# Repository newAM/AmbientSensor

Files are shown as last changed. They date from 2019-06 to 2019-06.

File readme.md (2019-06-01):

## Ambient Sensor

### What is it?
This project is a ambient environment sensor that gathers the luminosity, temperature, humidity, and pressure.  This data is transmitted in real time to my Home Assistant server via MQTT over Ethernet.

### Why?
I wanted to explore real-time adjustments of lighting, and window coverings to maintain constant light levels in a room, which requires high sample rates (multiple samples per second) for responsive adjustments.

When I started this project there were no high-sample rate luminosity sensors for home automation.  The devices that did exist either had low sample rates (minutes vs milliseconds), or were designed for scientific applications.

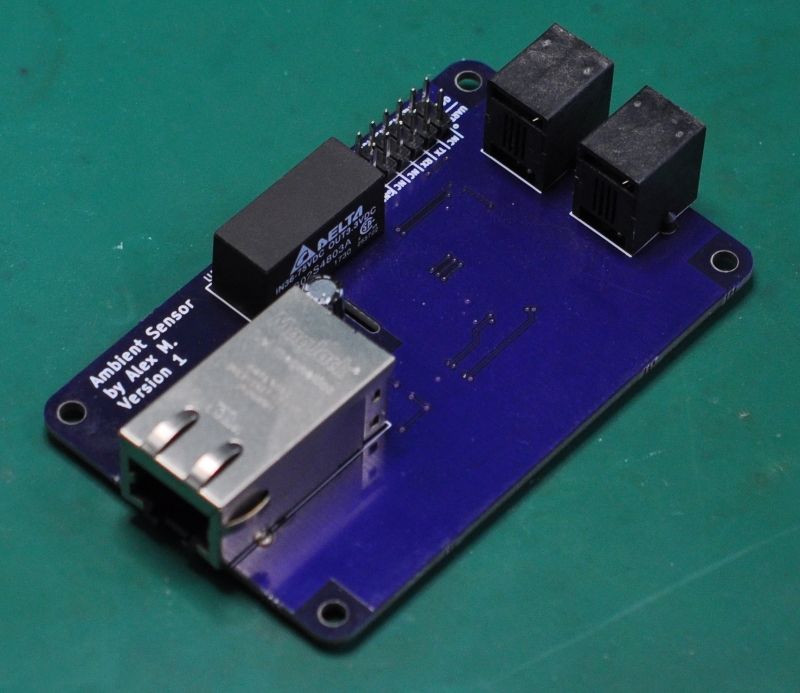
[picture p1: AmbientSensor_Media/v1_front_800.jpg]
v1_front_800


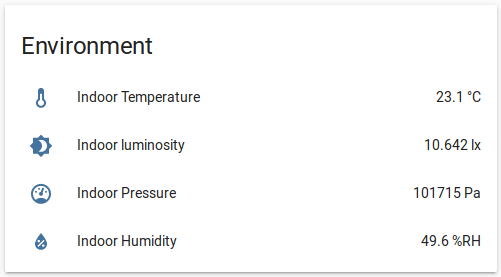
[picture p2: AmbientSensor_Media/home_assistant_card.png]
home_assistant_card


### Project Contents
* AmbientSensor_Code - firmware source code
* AmbientSensor_HomeAssisant - sample configuration for use with HomeAssistant
* AmbientSensor_KiCAD - schematic and PCB
* AmbientSensor_Peripheral - schematic and PCB for peripheral sensors
* AmbientSensor_Media - photos

### Prototype and Design
See [prototyping.md](prototyping.md) for the prototyping and design process.

### Software Used
* KiCAD 5.0.2
* GNU Make 4.1
* GNU gdb (GNU Tools for Arm Embedded Processors 7-2018-q3-update) 8.1.0.20180315
* GNU gcc (GNU Tools for Arm Embedded Processors 7-2018-q3-update) 7.3.1 20180622
* STM32CubeMX 5.1.0
* OpenOCD 0.10.0

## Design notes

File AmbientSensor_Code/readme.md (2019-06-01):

## Firmware README
The core code (HAL, FreeRTOS) was generated by [CubeMX](https://www.st.com/en/development-tools/stm32cubemx.html).  This is a piece of software from STM that generates all the boilerplate to get started with your STM32 microcontroller!  The code is already generated and in the repository; but I highly recommend using CubeMX if you need to change the auto-generated portions of the code.

### Windows Setup
Doing any sort of development with GNU tools on Windows is a pain.  I highly recommend dual booting Linux, running a virtual machine, or at the very least utilizing [Ubuntu on Windows](https://tutorials.ubuntu.com/tutorial/tutorial-ubuntu-on-windows).

### General Setup

Install packages
```
sudo apt install gcc-arm-none-eabi
sudo apt install gdb-arm-none-eabi
sudo apt install openocd
```

GDB for ARM may be covered by GDB multiarch for newer Ubuntu installs.  See [here](https://askubuntu.com/questions/1031103/how-to-install-gdb-arm-none-eabi-on-ubuntu-18-04).

### Building
CubeMX generates a tidy makefile for building the project.  There are other options that can tie into IDE's, but make is the only open source option.

### Call Make
Simply navigate into this directory and call make!

```
cd AmbientSensor_Code
make
```

The output will be available under `AmbientSensor_Code/build`.

### Programming and Debugging
The [ST-LINK/V2](https://www.st.com/en/development-tools/st-link-v2.html) is a cheap programmer and debugger for STM32 microcontrollers.

To use this with GDB I used [OpenOCD](http://openocd.org/), this exposes the USB debugger as a server that GDB can connect to.

On Linux the command to connect to the debugger looks like this
```
sudo openocd -f interface/stlink-v2.cfg -f target/stm32f0x.cfg
```

The OpenOCD server should then output something similar to:
```
Open On-Chip Debugger 0.10.0
Licensed under GNU GPL v2
For bug reports, read http://openocd.org/doc/doxygen/bugs.html
Info : auto-selecting first available session transport "hla_swd". To override use 'transport select <transport>'.
Info : The selected transport took over low-level target control. The results might differ compared to plain JTAG/SWD
adapter speed: 1000 kHz
adapter_nsrst_delay: 100
none separate
Info : Listening on port 6666 for tcl connections
Info : Listening on port 4444 for telnet connections
Info : Unable to match requested speed 1000 kHz, using 950 kHz
Info : Unable to match requested speed 1000 kHz, using 950 kHz
Info : clock speed 950 kHz
Info : STLINK v2 JTAG v28 API v2 SWIM v17 VID 0x0483 PID 0x374B
Info : using stlink api v2
Info : Target voltage: 3.260766
Info : stm32f0x.cpu: hardware has 4 breakpoints, 2 watchpoints
Info : Listening on port 3333 for gdb connections
```

Open GDB with this command:
```
arm-none-eabi-gdb build/AmbientSensor.elf
```

Then in the GDB interface you can connect to OpenOCD, reset the target and load the firmware.
```
(gdb) target remote localhost:3333
(gdb) monitor reset init
(gdb) monitor halt
(gdb) load
(gdb) c
```

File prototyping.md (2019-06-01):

## Overview
Ultimately, the input is the sensors, and the output is a value in Home Assistant
```
Sensors → STM32 Microcontroller → W5500 (TCP/IP + Ethernet PHY) → MQTT Server → Home Assistant
```

## Design Choices
### Sensors
There are two primary sensors for measuring the environment:
* [Bosch Sensortec BME280](https://www.bosch-sensortec.com/bst/products/all_products/bme280)
  * Temperature
  * Humidity
  * Pressure
* [Texas Instruments OPT3002](http://www.ti.com/product/OPT3002)
  * Luminosity

These sensors are connected to the main board with short RJ-11 cables that connect to the I2C bus on the microcontroller.
In the case of the BME280 the external connection was necessary to obtain accurate measurements, the main PCB is hotter than the ambient environment, and it would skew temperature readings.

For the OPT3002 the external connection is to allow for easy positioning of the sensor.

The BME280 was chosen over cheaper alternatives, such as the Aosong AM2032 (DHT22) because [this in depth review](http://www.kandrsmith.org/RJS/Misc/Hygrometers/calib_many.html#commentary) speaks highly of the BM280 as compared to similar devices.

### Microcontroller
The STM32F070CBTx was chosen because:
1. STM provides a very good hardware adapter layer (HAL) for their micro-controllers.
2. STM provides a FreeRTOS port for their micro-controllers.
3. I wanted to do something new, my past projects have been mostly AVR.

### Firmware
The firmware uses [FreeRTOS](https://www.freertos.org/) for scheduling, simply because it seemed like a fun learning experience, and it was!

The micro-controller has 4 main threads running:
1. A sampling thread for the BM280
2. A sampling thread for the OPT3002
3. DHCP client
4. MQTT client

The sampling threads take data from the sensors and place it in a queue for the MQTT task.
The MQTT client thread pops the samples from the queue and publishes them to the MQTT server.
The DHCP client thread handles the leasing of an IP from the DHCP server.

In the interest of learning new things I also made some poor choices intentionally; I implemented my own DHCP client code, and my own MQTT client code.  This was not the smart choice, since there are polished DHCP clients out there, such as the one in [LwIP](https://savannah.nongnu.org/projects/lwip/), but this was the _fun_ choice.

Instructions for using the firmware can be found [here](AmbientSensor_Code/readme.md).

## Prototyping
I wanted to get the PCB for this right on the first try, so I prototyped everything on a breadboard.

Naturally a lot of components were not available in 2.54mm friendly packages, I made some breadboard friendly boards for these components:
* [NCP1090](https://github.com/newAM/DevBoard_NCP1090)
* [OPT3002](https://github.com/newAM/Breakout_OPT3002)
* [W5500](https://github.com/newAM/DevBoard_W5500)
* [STM32F070CBTx](https://github.com/newAM/Breakout_STM32F070CBTx)
* [JTAG Adapter](https://github.com/newAM/Adapter_JTAG20PinTo6Pin)
* [PoE magjack 0813-1X1T-57-F](https://github.com/newAM/Breakout_0813-1X1T-57-F)

Debug tools used
* [ST-LINK/V2](https://www.st.com/en/development-tools/st-link-v2.html) - USB debugger/programmer
* [Saleae Logic 8](https://cad.saleae.com/products/saleae-logic-8?variant=6998355738685) - USB Logic analyzer
* [TP-Link TL-POE150S Injector](https://www.tp-link.com/us/business-networking/accessory/tl-poe150s/) - PoE Injector
* [FTDI Friend v1.0](https://www.adafruit.com/product/284) - USB to serial adapter

### Prototype Media
#### Breadboard Prototype
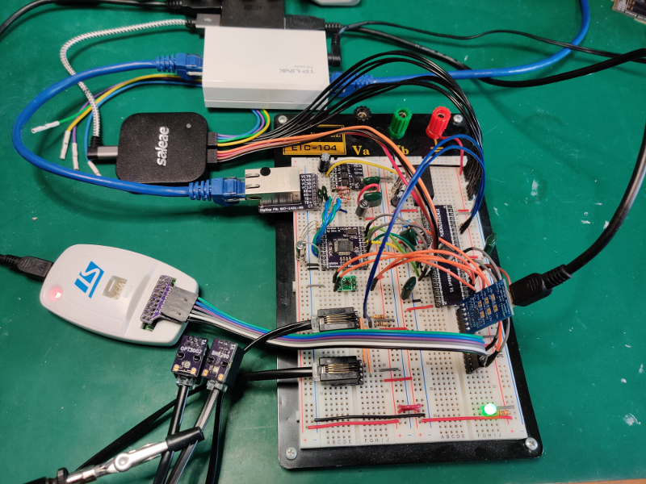
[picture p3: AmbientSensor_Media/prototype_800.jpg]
prototype_800


#### Prototype Thermal
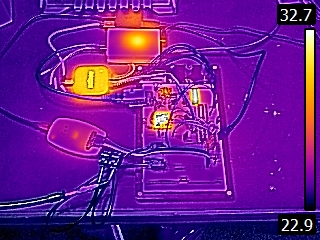
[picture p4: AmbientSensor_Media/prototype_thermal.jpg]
prototype_thermal


## V1 Hardware
The PCB is bigger than it needs to be because I was using the sample footprint that I have used for previous projects.
* [LoadCellOccupancy](https://github.com/newAM/LoadCellOccupany)
* [FanController](https://github.com/newAM/FanController)

### V1 Hardware Sensors
The sensors are on their own PCB with an RJ-11 connector.

#### BME280 sensor
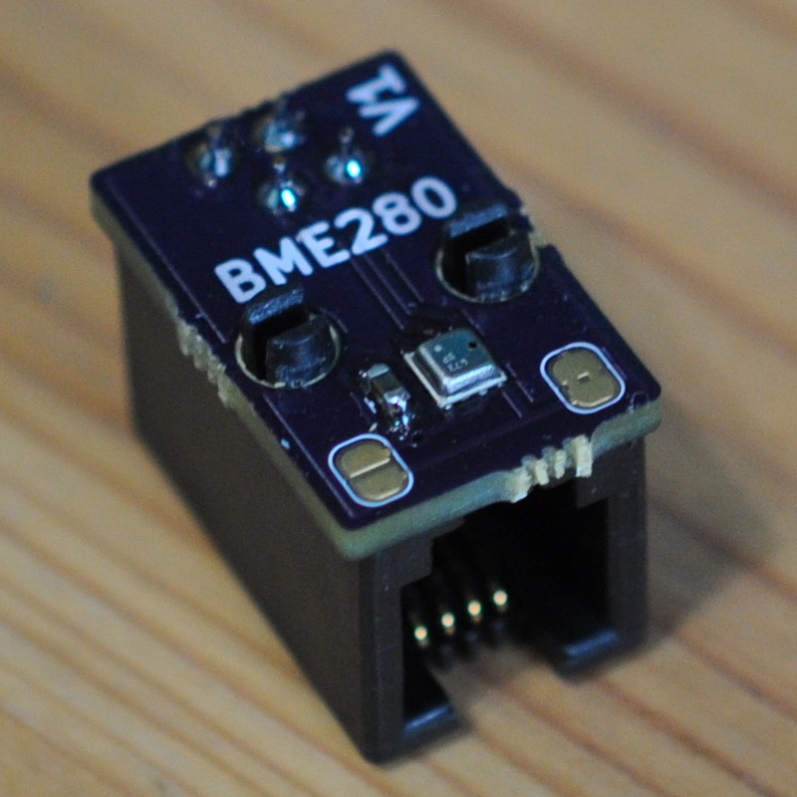
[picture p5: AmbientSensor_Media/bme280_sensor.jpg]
bme280_sensor


#### OPT3002 sensor
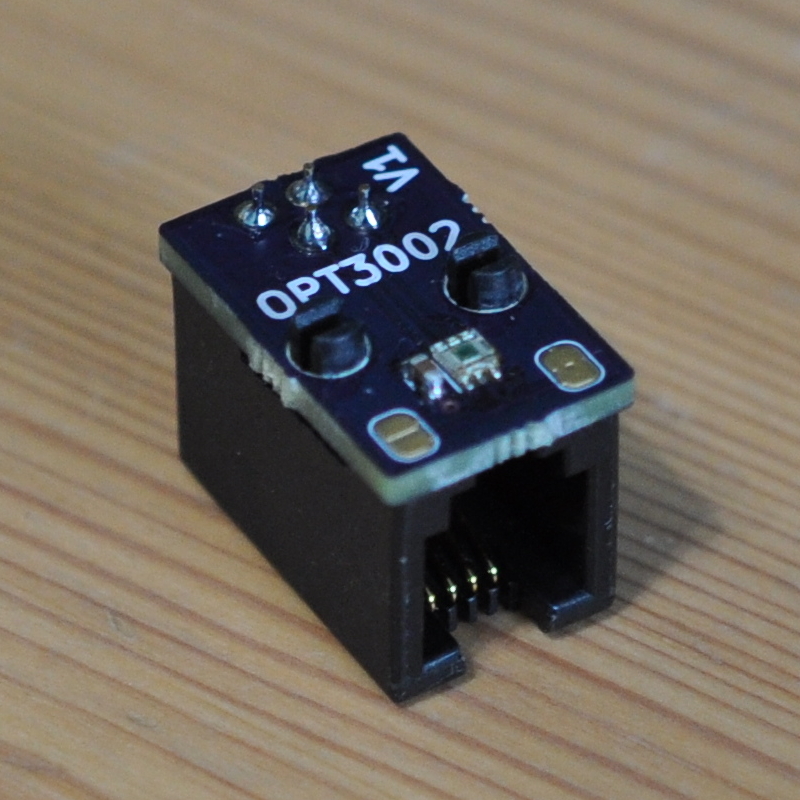
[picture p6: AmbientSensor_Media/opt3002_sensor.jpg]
opt3002_sensor


### V1 Hardware Media
#### Front
v1_front_800

#### Back
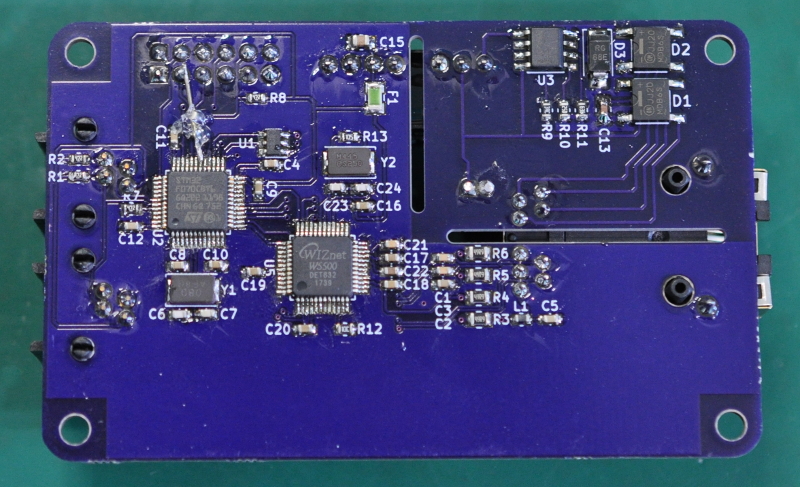
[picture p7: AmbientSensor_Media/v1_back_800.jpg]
v1_back_800


#### Front Thermal
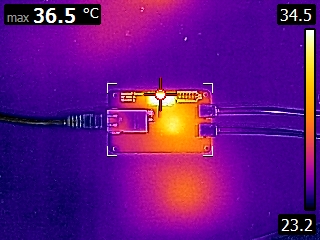
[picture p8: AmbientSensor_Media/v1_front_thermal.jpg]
v1_front_thermal


#### Back Thermal
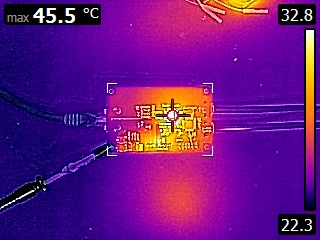
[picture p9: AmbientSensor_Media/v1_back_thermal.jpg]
v1_back_thermal


### V1 Hardware Erratum
* UASRT1_TX is connected to PA11, UASRT1_TX should be connected to PA9

### V1 Hardware Improvements
* The OPT3002 should be replaced with the OPT3001 since it has a response characteristic similar to the human eye.

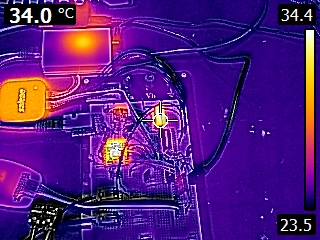
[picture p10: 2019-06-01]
AmbientSensor_Media/prototype_converter_hotspot.jpg

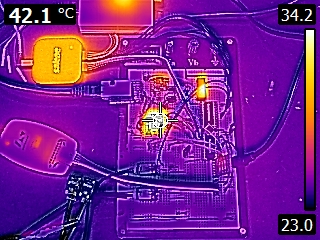
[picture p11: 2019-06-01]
AmbientSensor_Media/prototype_w5500_hotspot.jpg

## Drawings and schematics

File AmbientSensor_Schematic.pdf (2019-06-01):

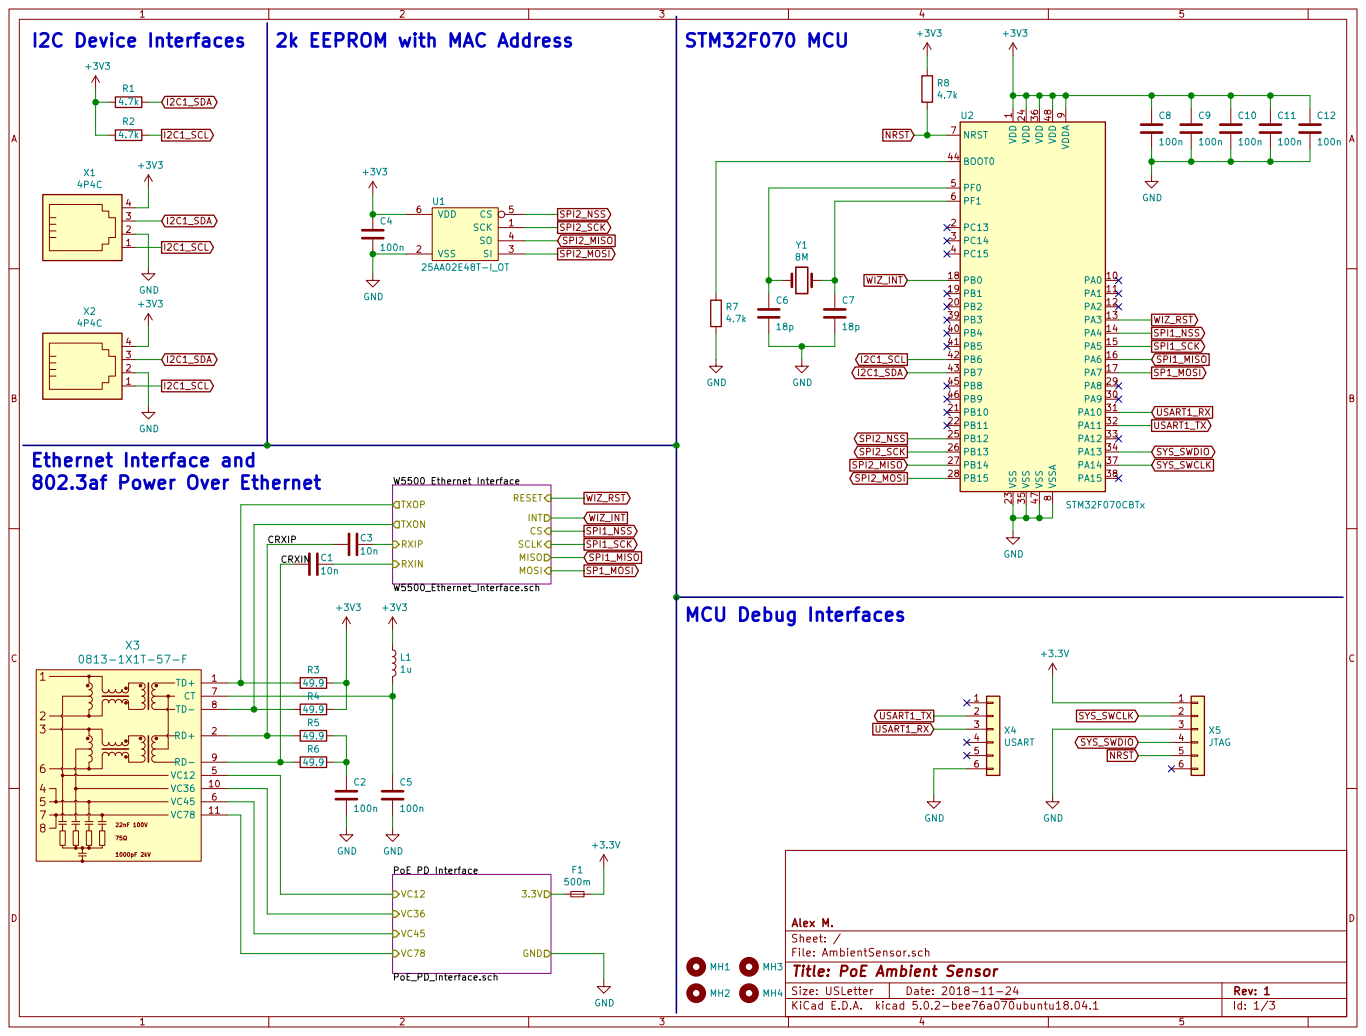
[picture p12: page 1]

1 VDD 24 VDD 36 VDD 48 VDDA

9 VSS 23 VSS 35 VSS 47 VSSA

I2C1_SDA
3.3V W5500 Ethernet Interface W5500_Ethernet_Interface.sch CS MISO MOSI SCLK RESET RXIP RXIN
10n GND

Id: 1/3 Title: PoE Ambient Sensor File: AmbientSensor.sch Sheet: / Alex M.

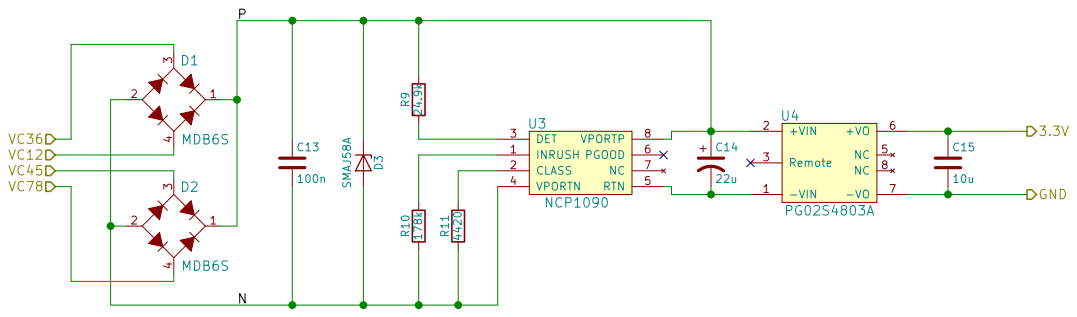
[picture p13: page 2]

File: PoE_PD_Interface.sch Sheet: /PoE PD Interface/ Alex M. VC12

Id: 2/3 Title: PoE Ambient Sensor

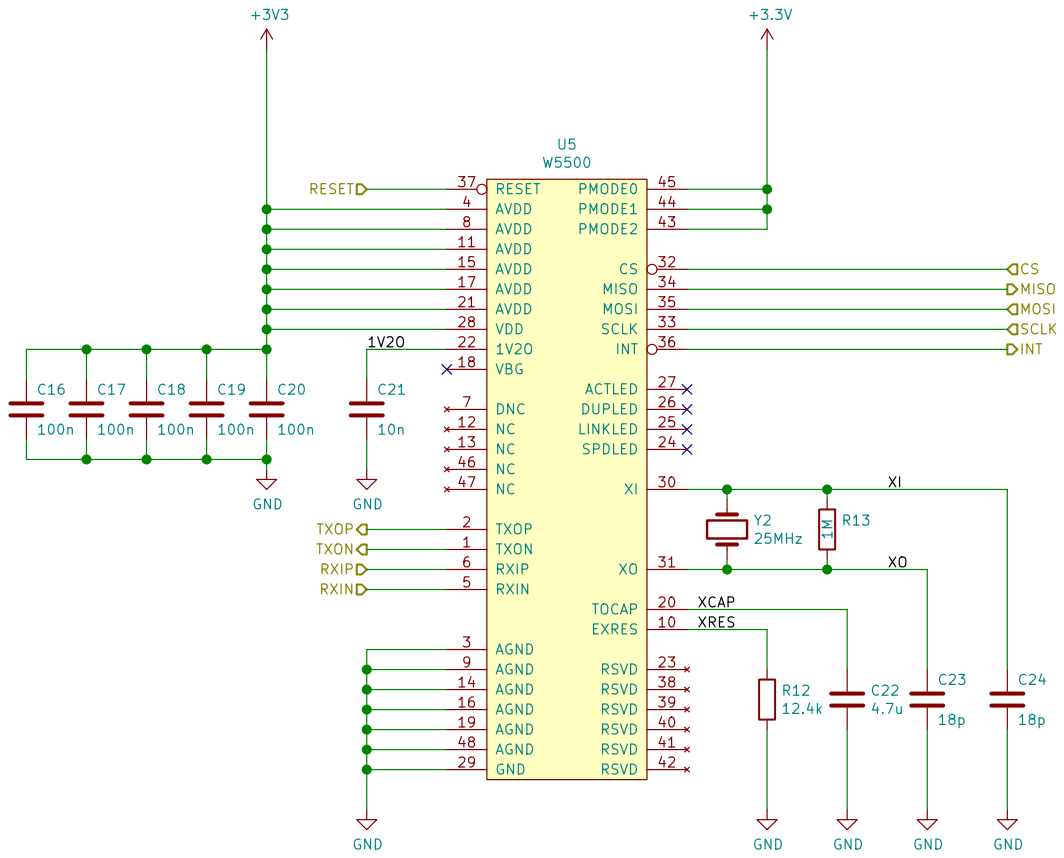
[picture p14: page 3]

File: W5500_Ethernet_Interface.sch Sheet: /W5500 Ethernet Interface/ Alex M. R12

Id: 3/3 Title: PoE Ambient Sensor

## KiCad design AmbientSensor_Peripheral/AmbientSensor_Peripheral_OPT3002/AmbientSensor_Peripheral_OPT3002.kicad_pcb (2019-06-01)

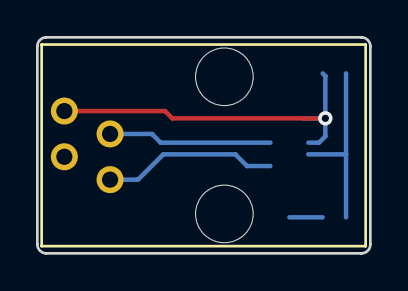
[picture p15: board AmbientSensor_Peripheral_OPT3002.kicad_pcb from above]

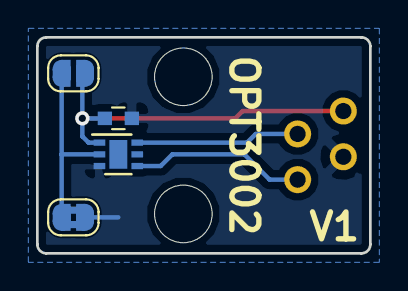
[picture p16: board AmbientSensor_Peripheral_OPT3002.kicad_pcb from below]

Board: 2 copper layers, 18.5 x 12.0 mm, 5 parts (4 on the bottom side), 5 nets.

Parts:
C1: 100u; C_0603
J1: NO; SolderJumper-2_P1.3mm_Open_RoundedPad1.0x1.5mm
J2: NC; SolderJumper-2_P1.3mm_Bridged2Bar_RoundedPad1.0x1.5mm
U1: OPT3002; DFN-6-1EP_2x2mm_Pitch0.65mm
X1: RJ22; A-2004-3-4-LP-N-R

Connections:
+3V3: C1.1, J1.1, U1.1, X1.4
GND: C1.2, J2.1, U1.3, X1.2
unnamed: J1.2, J2.2, U1.2
SCL: U1.4, X1.1
SDA: U1.6, X1.3

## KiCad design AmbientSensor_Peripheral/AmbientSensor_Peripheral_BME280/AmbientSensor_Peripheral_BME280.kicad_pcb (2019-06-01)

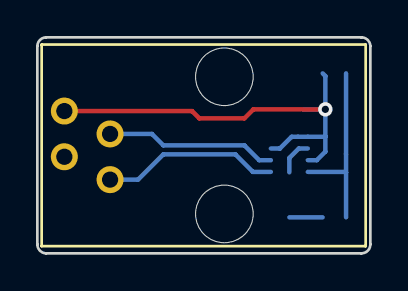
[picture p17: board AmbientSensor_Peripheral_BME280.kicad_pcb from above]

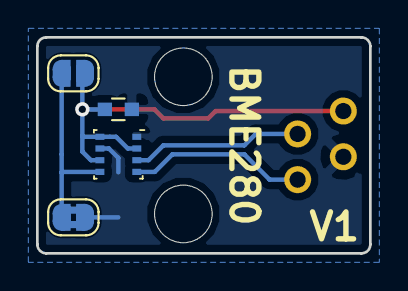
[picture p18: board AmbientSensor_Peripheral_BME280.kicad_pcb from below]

Board: 2 copper layers, 18.5 x 12.0 mm, 5 parts (4 on the bottom side), 5 nets.

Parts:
C1: 100u; C_0603
J1: NO; SolderJumper-2_P1.3mm_Open_RoundedPad1.0x1.5mm
J2: NC; SolderJumper-2_P1.3mm_Bridged2Bar_RoundedPad1.0x1.5mm
U1: BME280; Bosch_LGA-8_2.5x2.5mm_Pitch0.65mm_ClockwisePinNumbering
X1: RJ22; A-2004-3-4-LP-N-R

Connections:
+3V3: C1.1, J1.1, U1.2, U1.6, U1.8, X1.4
GND: C1.2, J2.1, U1.1, U1.7, X1.2
unnamed: J1.2, J2.2, U1.5
SCL: U1.4, X1.1
SDA: U1.3, X1.3

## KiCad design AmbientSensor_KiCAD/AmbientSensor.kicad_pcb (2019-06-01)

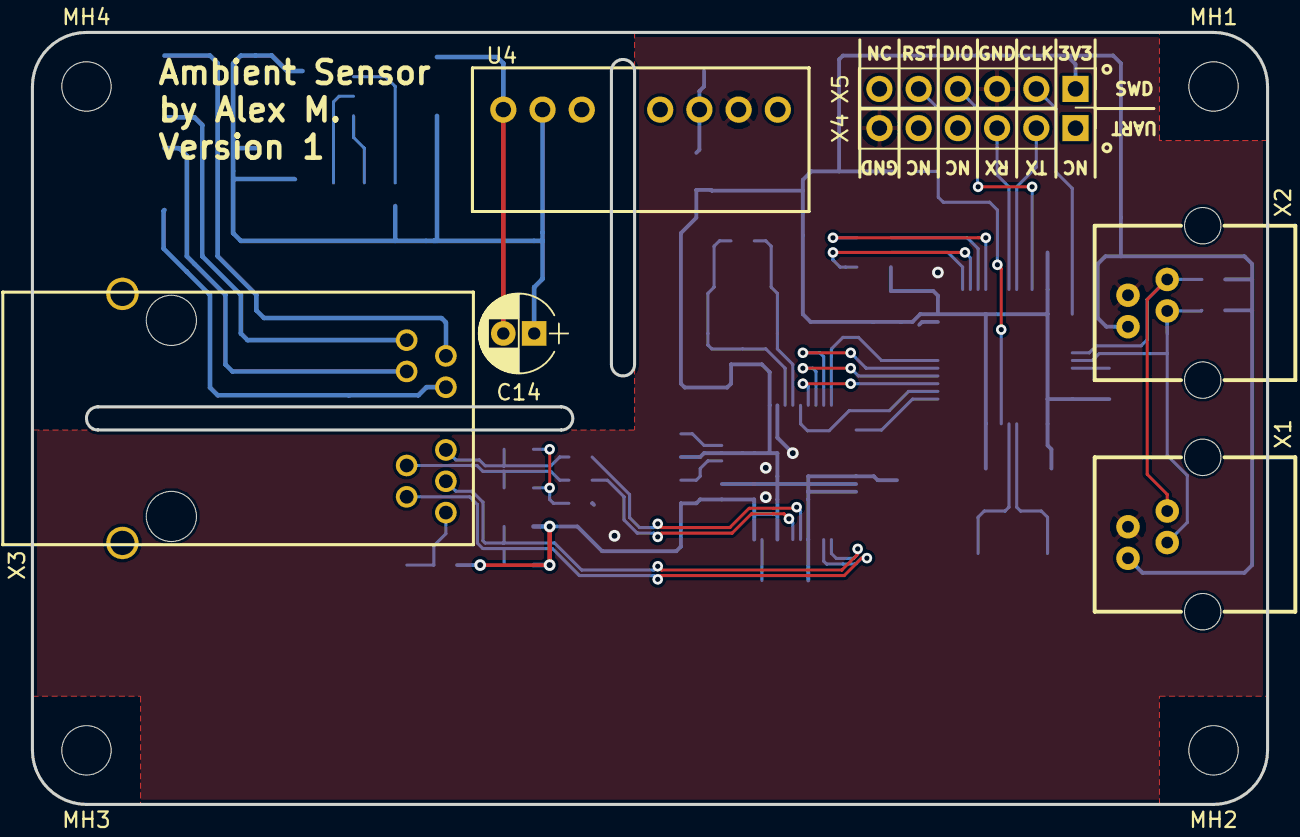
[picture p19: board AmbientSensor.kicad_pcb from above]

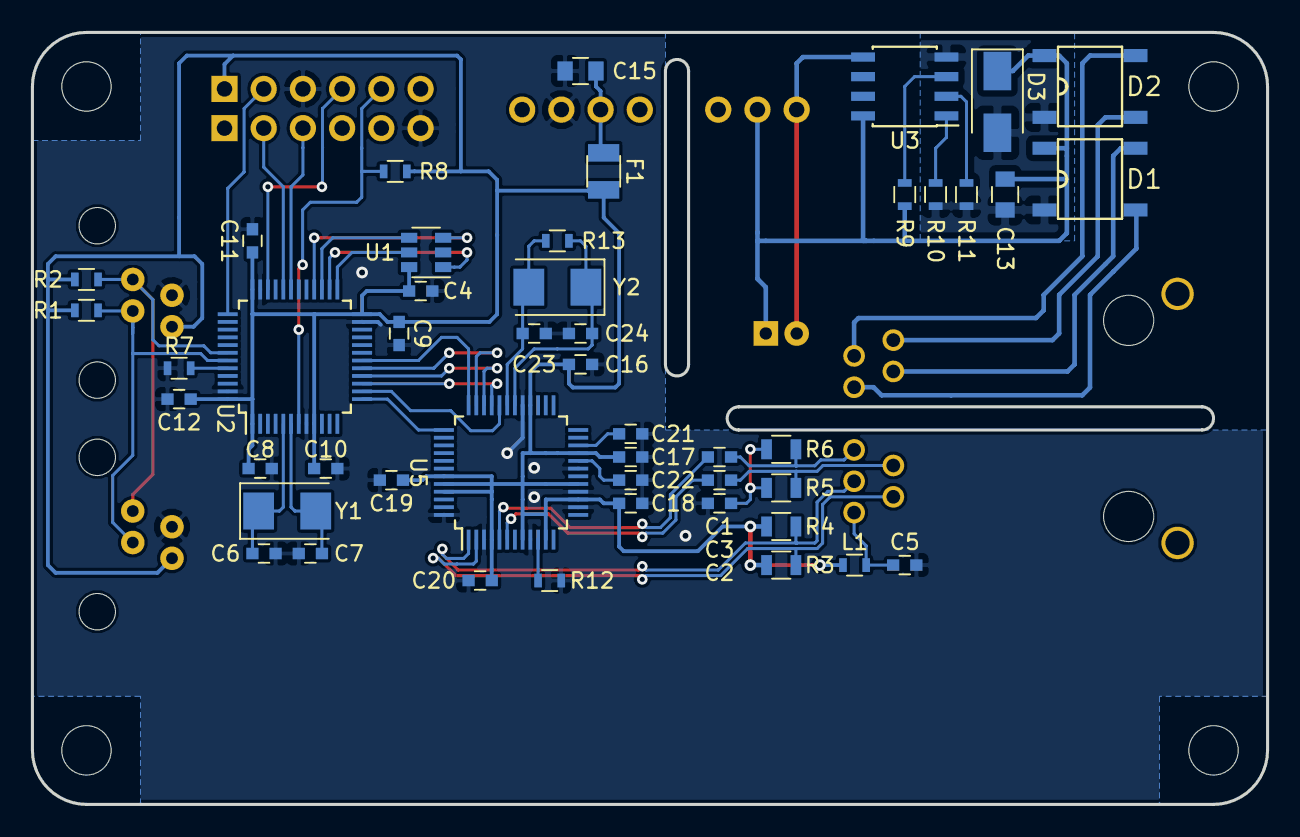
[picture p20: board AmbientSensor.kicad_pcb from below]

Board: 2 copper layers, 80.0 x 50.0 mm, 58 parts (47 on the bottom side), 46 nets.

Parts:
C1, C3, C21: 10n; C_0603
C2, C4, C5, C8, C9, C10, C11, C12, C16, C17, C18, C19, C20: 100n; C_0603
C6, C7, C23, C24: 18p; C_0603
C13: 100n; C_0805
C14: 22u; CP_Radial_D5.0mm_P2.00mm
C15: 10u; C_0805
C22: 4.7u; C_0603
D1, D2: MDB6S; Micro-DIP-4
D3: SMAJ58A; D_SMA
F1: 500m; Fuse_SMD1206_Reflow
L1: 1u; L_0603
MH1, MH2, MH3, MH4: MountingHole; MountingHole_3.2mm_M3
R1, R2, R7, R8: 4.7k; R_0603
R3, R4, R5, R6: 49.9; R_0805
R9: 24.9k; R_0603
R10: 178k; R_0603
R11: 4420; R_0603
R12: 12.4k; R_0603
R13: 1M; R_0603
U1: 25AA02E48T-I_OT; SOT-23-6
U2: STM32F070CBTx; LQFP-48_7x7mm_Pitch0.5mm
U3: NCP1090; SOIC-8_3.9x4.9mm_Pitch1.27mm
U4: PG02S4803A; PG02S
U5: W5500; LQFP-48_7x7mm_Pitch0.5mm
X1, X2: 4P4C; E5544-60LU22-L
X3: 0813-1X1T-57-F; 0813-1X1T-57-F_RJ45-Jack
X4: USART; Pin_Header_Straight_1x06_Pitch2.54mm
X5: JTAG; Pin_Header_Straight_1x06_Pitch2.54mm
Y1: 8M; Crystal_SMD_5032-2pin_5.0x3.2mm
Y2: 25MHz; Crystal_SMD_5032-2pin_5.0x3.2mm

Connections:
+3V3: C4.1, C8.1, C9.1, C10.1, C11.1, C12.1, C16.1, C17.1, C18.1, C19.1, C20.1, F1.2, L1.1, R1.1, R2.1, R3.1, R4.1, R8.1, U1.6, U2.1, U2.9, U2.24, U2.36, U2.48, U5.4, U5.8, U5.11, U5.15, U5.17, U5.21, U5.28, U5.43, U5.44, U5.45, X1.4, X2.4, X5.1
/CRXIN: C1.2, R6.2, X3.9
/CRXIP: C3.2, R5.2, X3.2
/PoE PD Interface/3.3V: C15.1, F1.1, U4.6
/PoE PD Interface/N: C13.2, D1.2, D2.2, D3.2, R10.1, R11.1, U3.4
/PoE PD Interface/P: C13.1, C14.1, D1.1, D2.1, D3.1, R9.2, U3.8, U4.2
/PoE PD Interface/VC12: D1.4, X3.5
/PoE PD Interface/VC36: D1.3, X3.10
/PoE PD Interface/VC45: D2.3, X3.6
/PoE PD Interface/VC78: D2.4, X3.11
/W5500 Ethernet Interface/1V2O: C21.1, U5.22
/W5500 Ethernet Interface/RXIN: C1.1, U5.5
/W5500 Ethernet Interface/RXIP: C3.1, U5.6
/W5500 Ethernet Interface/TXON: R4.2, U5.1, X3.8
/W5500 Ethernet Interface/TXOP: R3.2, U5.2, X3.1
/W5500 Ethernet Interface/XCAP: C22.1, U5.20
/W5500 Ethernet Interface/XI: C24.1, R13.1, U5.30, Y2.1
/W5500 Ethernet Interface/XO: C23.1, R13.2, U5.31, Y2.2
/W5500 Ethernet Interface/XRES: R12.1, U5.10
GND: C2.2, C4.2, C5.2, C6.2, C7.2, C8.2, C9.2, C10.2, C11.2, C12.2, C15.2, C16.2, C17.2, C18.2, C19.2, C20.2, C21.2, C22.2, C23.2, C24.2, R7.1, R12.2, U1.2, U2.8, U2.23, U2.35, U2.47, U4.7, U5.3, U5.9, U5.14, U5.16, U5.19, U5.29, U5.48, X1.2, X2.2, X4.6, X5.3
I2C1_SCL: R2.2, U2.42, X1.1, X2.1
I2C1_SDA: R1.2, U2.43, X1.3, X2.3
NRST: R8.2, U2.7, X5.5
unnamed: C2.1, R5.1, R6.1
unnamed: C5.1, L1.2, X3.7
unnamed: C6.1, U2.5, Y1.1
unnamed: C7.1, U2.6, Y1.2
unnamed: C14.2, U3.5, U4.1
unnamed: R7.2, U2.44
unnamed: R9.1, U3.3
unnamed: R10.2, U3.1
unnamed: R11.2, U3.2
SP1_MOSI: U2.17, U5.35
SPI1_MISO: U2.16, U5.34
SPI1_NSS: U2.14, U5.32
SPI1_SCK: U2.15, U5.33
SPI2_MISO: U1.4, U2.27
SPI2_MOSI: U1.3, U2.28
SPI2_NSS: U1.5, U2.25
SPI2_SCK: U1.1, U2.26
SYS_SWCLK: U2.37, X5.2
SYS_SWDIO: U2.34, X5.4
USART1_RX: U2.31, X4.3
USART1_TX: U2.32, X4.2
WIZ_INT: U2.18, U5.36
WIZ_RST: U2.13, U5.37

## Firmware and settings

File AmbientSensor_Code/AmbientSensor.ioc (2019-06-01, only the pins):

Mcu.UserName=STM32F070CBTx
PA10.Signal=USART1_RX
PA13.Signal=SYS_SWDIO
PA14.Signal=SYS_SWCLK
PA3.GPIO_Label=WIZ_RST
PA3.Signal=GPIO_Output
PA4.GPIO_Label=WIZ_CS
PA4.Signal=GPIO_Output
PA5.Signal=SPI1_SCK
PA6.Signal=SPI1_MISO
PA7.Signal=SPI1_MOSI
PA9.Signal=USART1_TX
PB0.GPIO_Label=WIZ_INT
PB0.Signal=GPXTI0
PB12.GPIO_Label=EEPROM_CS
PB12.Signal=GPIO_Output
PB13.Signal=SPI2_SCK
PB14.Signal=SPI2_MISO
PB15.Signal=SPI2_MOSI
PB6.Signal=I2C1_SCL
PB7.Signal=I2C1_SDA
PF0-OSC_IN.Signal=RCC_OSC_IN
PF1-OSC_OUT.Signal=RCC_OSC_OUT

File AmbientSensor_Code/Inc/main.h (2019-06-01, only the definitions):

#define WIZ_RST_Pin GPIO_PIN_3
#define WIZ_RST_GPIO_Port GPIOA
#define WIZ_CS_Pin GPIO_PIN_4
#define WIZ_CS_GPIO_Port GPIOA
#define WIZ_INT_Pin GPIO_PIN_0
#define WIZ_INT_GPIO_Port GPIOB
#define WIZ_INT_EXTI_IRQn EXTI0_1_IRQn
#define EEPROM_CS_Pin GPIO_PIN_12
#define EEPROM_CS_GPIO_Port GPIOB

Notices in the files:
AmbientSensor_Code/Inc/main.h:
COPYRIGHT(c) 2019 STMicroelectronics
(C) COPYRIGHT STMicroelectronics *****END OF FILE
